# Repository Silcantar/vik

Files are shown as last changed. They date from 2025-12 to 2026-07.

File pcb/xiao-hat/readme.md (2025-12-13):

# XIAO VIK Hat

## Overview

This is a simple PCB to add a VIK connector to a Seeed XIAO microcontroller
board. It is mainly intended for the nRF52840 XIAO variant but probably works
for the other variants as well.

The XIAO is surface-mounted to the hat, which allows the BATT+ pad to be
connected as well as making for a lower-profile assembly.

A solder jumper is provided to select which power source is used for the VIK 5V
pin. By default this pin is connected to the BATT+ pad on the XIAO. The
connection can be changed to the USB 5V pin by severing the default jumper and
soldering the other.

## Fabrication and BOM

For PCB fabrication, you can use the files in the `production` folder.

* `xiao-hat.zip` - the file used to fabricate the pcb
* `bom.csv` - used for PCBA. You can also use the part numbers in this file to look up the exact parts as [lcsc.com](https://lcsc.com)
* `positions.csv` - used for PCBA

Using the 3 files above, this has been tested at [jlcpcb.com](https://jlcpcb.com)
These files were generated by the [KiCAD JLCPCB tools plugin](https://github.com/Bouni/kicad-jlcpcb-tools).

## VIK module certification

| Category | Classification | Response |
| --- | --- | --- |
| FPC connector | Required | :heavy_check_mark: |
| Breakout pins | Recommended | :x: |
| Uses: SPI | Optional | :x: |
| SPI used for SPI only | Strongly recommended | :x: |
| Uses: I2C | Optional | :x: |
| I2C used for I2C only | Strongly Recommended | :x: |
| I2C pull ups | Required | :x: |
| Uses: RGB | Optional | :x: |
| Uses: Extra GPIO 1 | Optional | :x: |
| Uses: Extra GPIO 2 | Optional | :x: |
| Standard PCB Size/Mount | Strongly recommended | :x: |

## PCB images

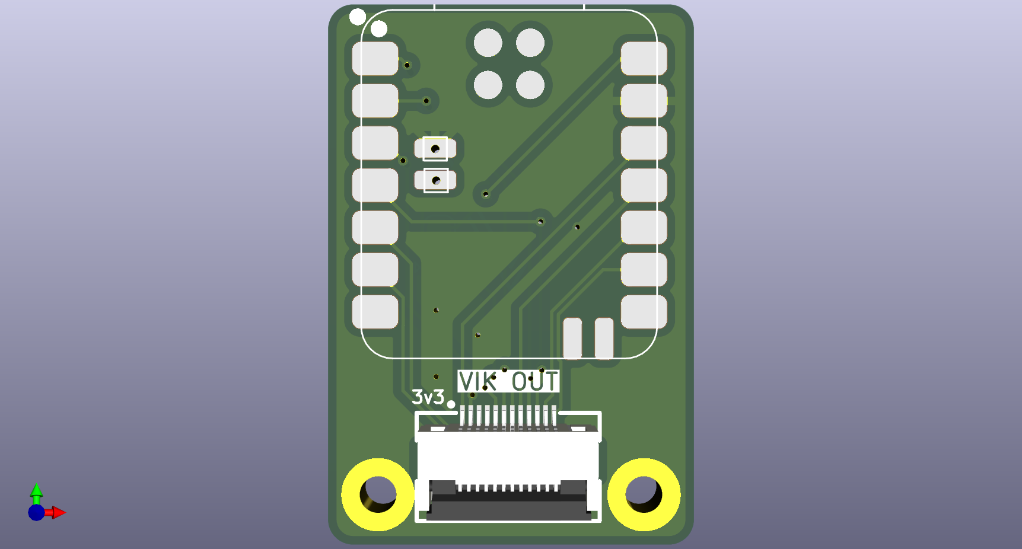
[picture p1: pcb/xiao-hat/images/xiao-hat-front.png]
pcb front


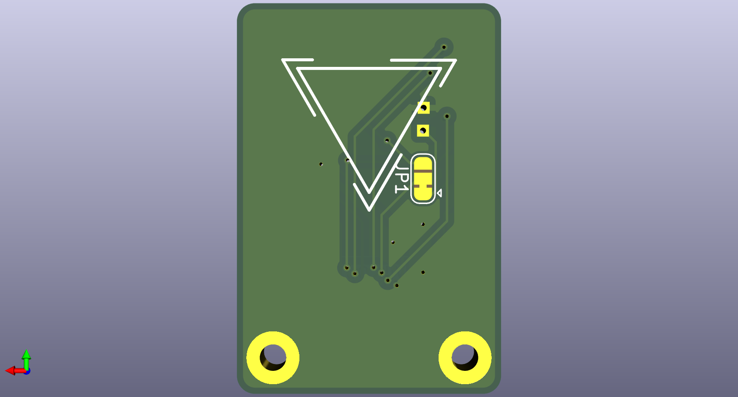
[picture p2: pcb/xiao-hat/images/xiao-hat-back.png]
pcb back


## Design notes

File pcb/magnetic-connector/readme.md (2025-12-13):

# Magnetic Connectors

## Overview

This is a pair of PCBs that adapt a VIK FPC cable to a 12-pin, 2.2mm pitch
magnetic pogo pin connector and back. The pinout of the magnetic connectors is
equivalent to the standard VIK breakout pin layout.

## Fabrication and BOM

For PCB fabrication, you can use the files in the `production` folder.

* `magnetic-connector.zip` - the file used to fabricate the pcb
* `bom.csv` - used for PCBA. You can also use the part numbers in this file to
  look up the exact parts as [lcsc.com](https://lcsc.com)
* `positions.csv` - used for PCBA

Using the 3 files above, this has been tested at [jlcpcb.com](https://jlcpcb.com)

## VIK module certification

| Category | Classification | Response |
| --- | --- | --- |
| FPC connector | Required | :heavy_check_mark: |
| Breakout pins | Recommended | :heavy_check_mark:*|
| Uses: SPI | Optional | :x: |
| SPI used for SPI only | Strongly recommended | :x: |
| Uses: I2C | Optional | :x: |
| I2C used for I2C only | Strongly Recommended | :x: |
| I2C pull ups | Required | :x: |
| Uses: RGB | Optional | :x: |
| Uses: Extra GPIO 1 | Optional | :x: |
| Uses: Extra GPIO 2 | Optional | :x: |
| Standard PCB Size/Mount | Strongly recommended | :x: |

\* If you count the footprint of the magnetic connector.

## PCB images

### horizontal fpc

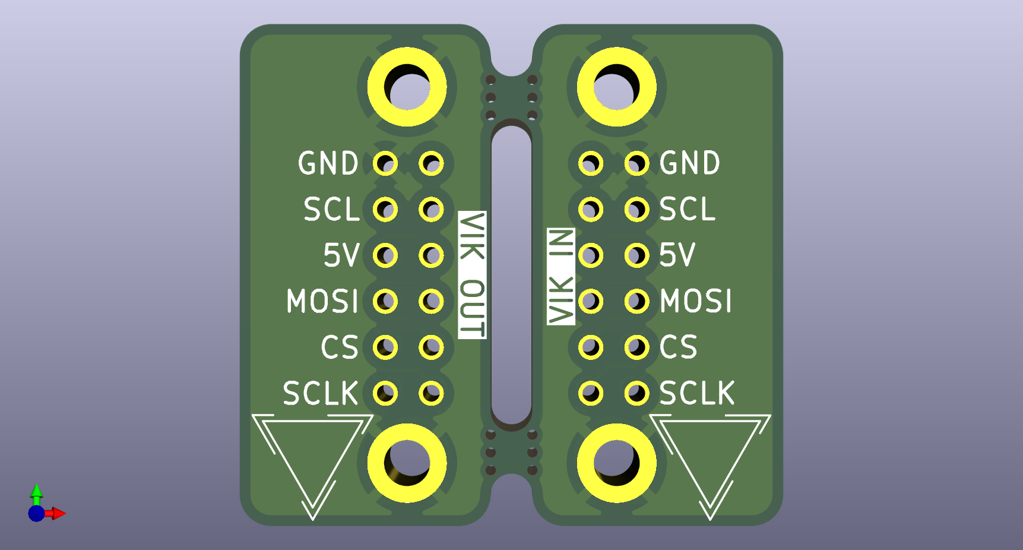
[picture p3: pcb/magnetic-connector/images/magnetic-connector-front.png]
pcb front


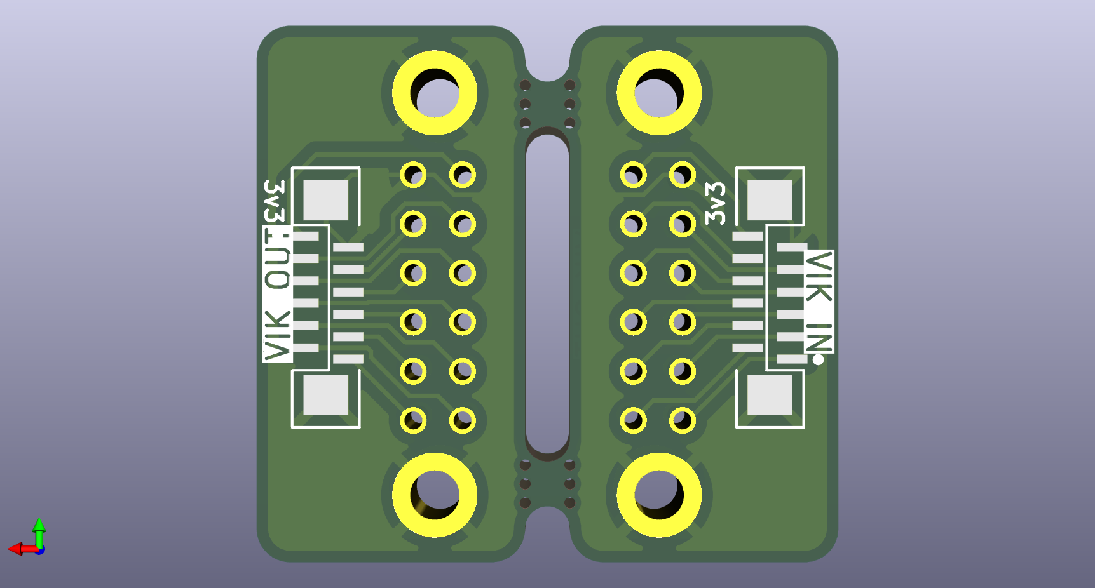
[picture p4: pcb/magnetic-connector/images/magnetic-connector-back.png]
pcb back


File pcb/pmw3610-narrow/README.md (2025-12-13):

# VIK-Compliant PMW3610 Trackball PCB - XXS Version

## Overview

This is a slightly modified version of ykz89's PMW3610-xxs module. The MOTION
pin of the sensor is moved from the VIK MOSI pin to GP2 to make the module
compliant with the VIK standard.

## Fabrication and BOM

For PCB fabrication, you can use the files in the jlcpcb/production_files folder.

* `pmw3610-xxs-compliant.zip` - the file used to fabricate the pcb
* `bom.csv` - used for PCBA. You can also use the part numbers in this file to look up the exact parts as [lcsc.com](https://lcsc.com)
* `positions.csv` - used for PCBA

Using the 3 files above, this has been tested at [jlcpcb.com](https://jlcpcb.com)
These files were generated by the [KiCAD JLCPCB tools plugin](https://github.com/Bouni/kicad-jlcpcb-tools).

## VIK module certification

| Category | Classification | Response |
| --- | --- | --- |
| FPC connector | Required | :heavy_check_mark: |
| Breakout pins | Recommended | :x: |
| Uses: SPI | Optional | :heavy_check_mark: |
| SPI used for SPI only | Strongly recommended | :heavy_check_mark: |
| Uses: I2C | Optional | :x: |
| I2C used for I2C only | Strongly Recommended | :x: |
| I2C pull ups | Required | :x: |
| Uses: RGB | Optional | :x: |
| Uses: Extra GPIO 1 | Optional | :x: |
| Uses: Extra GPIO 2 | Optional | :heavy_check_mark: |
| Standard PCB Size/Mount | Strongly recommended | :x: |

## PCB images

pcb front

pcb back

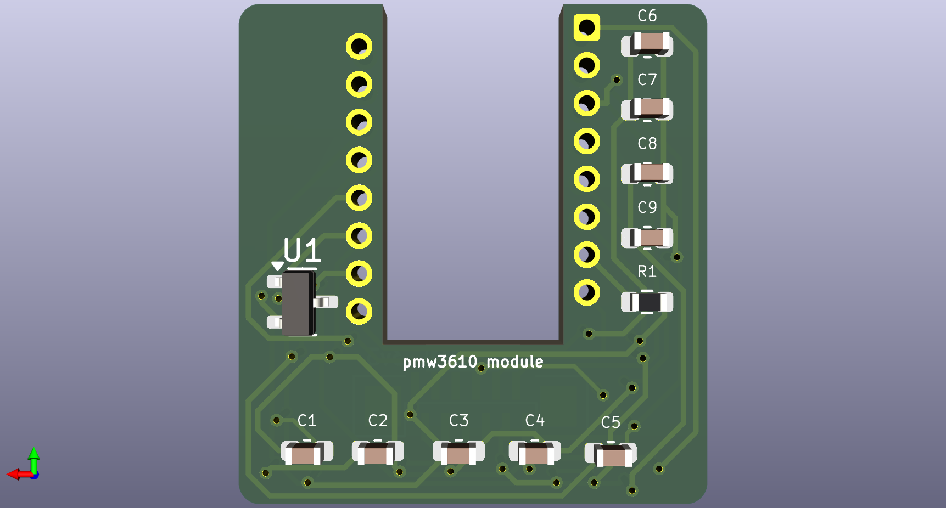
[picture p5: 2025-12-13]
pcb/pmw3610-narrow/images/pmw3610-narrow-back.png

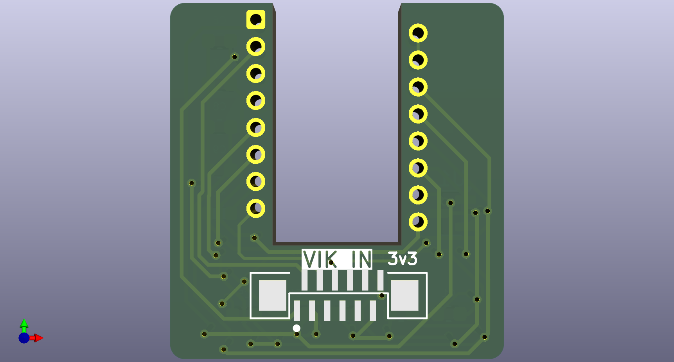
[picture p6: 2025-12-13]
pcb/pmw3610-narrow/images/pmw3610-narrow-front.png

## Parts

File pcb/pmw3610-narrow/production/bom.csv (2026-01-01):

Designator | Footprint | Quantity | Value | LCSC Part #
C1 | 0603 | 1 | 1u | C14663
C2 | 0603 | 1 | 1u | C15849
C3, C8 | 0603 | 2 | 100n | C19666
C4 | 0603 | 1 | 10n | C19666
C5 | 0603 | 1 | 100n (X7R) | C19666
C6 | 0603 | 1 | 10u (X7R) | C19666
C7 | 0603 | 1 | 10n (X7R) | C19666
C9 | 0603 | 1 | 3.3u/25V | C19666
J2 | vik-module-connector-vertical | 1 | vik-module-connector
R1 | 0603 | 1 | 2M | C22976
U1 | SOT-23 | 1 | MCP1700T-1802E/TT | C150796
U2 | PMW3610DM-SUDU 16Pin | 1 | PMW3610

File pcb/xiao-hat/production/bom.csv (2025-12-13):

Designator | Footprint | Quantity | Value | LCSC Part #
J6 | vik-keyboard-connector-horizontal | 1 | VIK_OUT
U4 | XIAO-nRF52840-SMD | 1 | XIAO-nRF52840-SMD

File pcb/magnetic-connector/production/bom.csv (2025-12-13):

Designator | Footprint | Quantity | Value | LCSC Part #
_6, _5, _2, |  | 4
_4, _3 | vik-logo-small | 2 | vik-logo-small
J10 | vik-module-throughole-2.2mm | 1 | MAG_CONN_IN
J7 | vik-module-connector-vertical | 1 | VIK_IN
J8 | vik-keyboard-connector-vertical | 1 | VIK_OUT
J9 | vik-keyboard-throughole-2.2mm | 1 | MAG_CONN_OUT

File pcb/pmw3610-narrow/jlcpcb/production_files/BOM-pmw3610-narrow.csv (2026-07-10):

Comment | Designator | Footprint | LCSC | Quantity
100n | C3,C8 | C_0603_1608Metric_Pad1.08x0.95mm_HandSolder | C14663 | 2
100n (X7R) | C5 | C_0603_1608Metric_Pad1.08x0.95mm_HandSolder | C14663 | 1
10n | C4 | C_0603_1608Metric_Pad1.08x0.95mm_HandSolder | C57112 | 1
10n (X7R) | C7 | C_0603_1608Metric_Pad1.08x0.95mm_HandSolder | C57112 | 1
10u (X7R) | C6 | C_0603_1608Metric_Pad1.08x0.95mm_HandSolder | C19702 | 1
1u | C1,C2 | C_0603_1608Metric_Pad1.08x0.95mm_HandSolder | C15849 | 2
2M | R1 | R_0603_1608Metric_Pad0.98x0.95mm_HandSolder | C2930148 | 1
3.3u/25V | C9 | C_0603_1608Metric_Pad1.08x0.95mm_HandSolder | C51412 | 1
MG6208T3-18 | U1 | SOT-23 | C22395363 | 1
vik-module-connector | J2 | vik-module-connector-horizontal-mini | C2906115 | 1

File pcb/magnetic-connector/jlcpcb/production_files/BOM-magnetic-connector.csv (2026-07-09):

Comment | Designator | Footprint | LCSC | Quantity
CLAMP0504DT | U1,U2,U3,U4,U5,U6 | SOT-23-6 | C2688137 | 6
SMD0805-050-16V | F1,F2,F3,F4 | Fuse_0805_2012Metric | C2833485 | 4
VIK_IN | J_VIK_HOST1 | vik-module-connector-horizontal | C2856799 | 1
VIK_OUT | J_VIK_CLI1 | vik-keyboard-connector-horizontal | C2856799 | 1
MAG_CONN_IN | J_MC_CLI1 | vik-module-throughole-2.2mm |  | 1
MAG_CONN_OUT | J_MC_HOST1 | vik-keyboard-throughole-2.2mm |  | 1

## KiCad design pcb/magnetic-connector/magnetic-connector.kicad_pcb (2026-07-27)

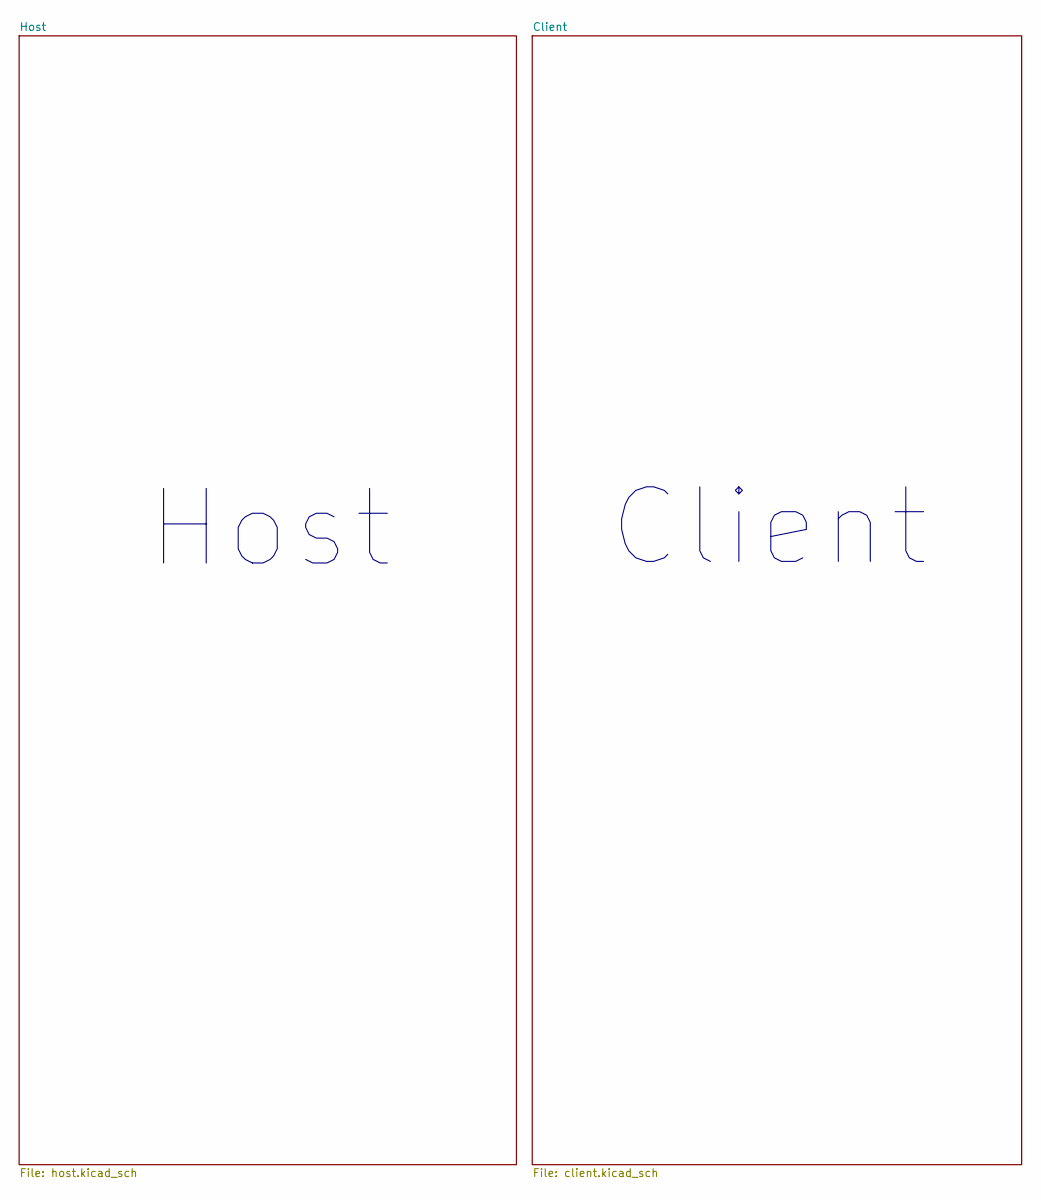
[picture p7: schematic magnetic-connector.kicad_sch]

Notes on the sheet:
Host
Client

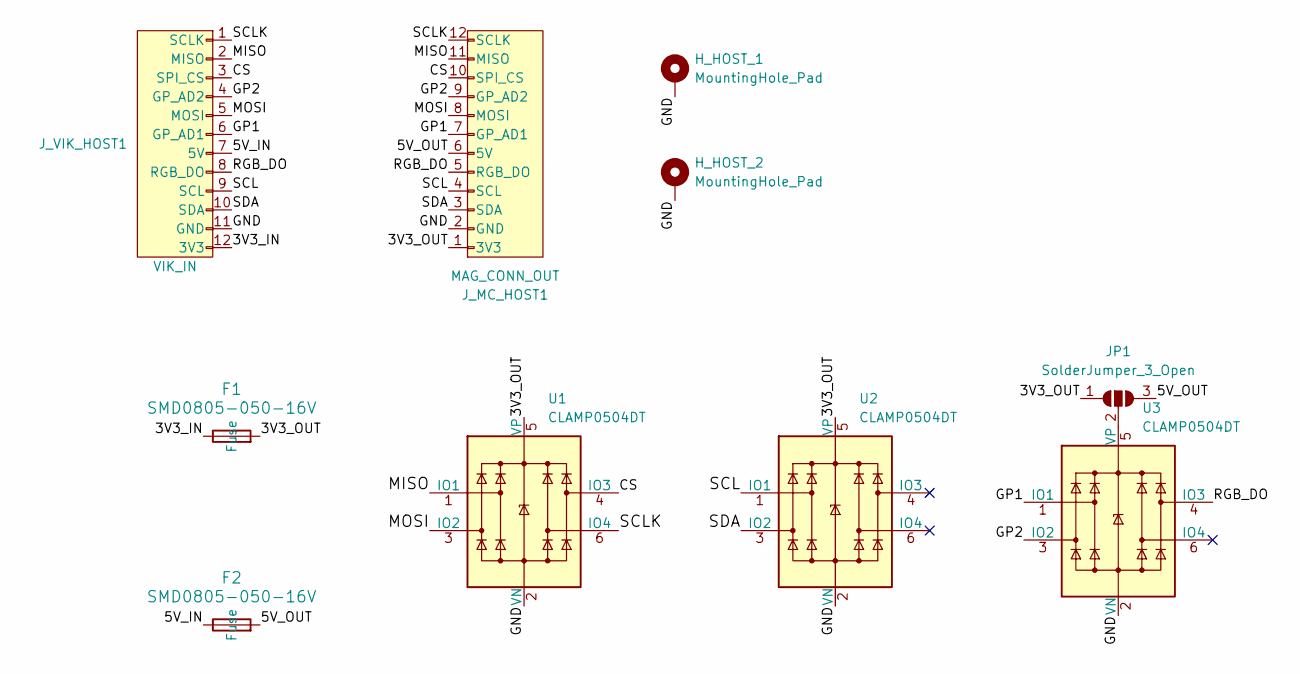
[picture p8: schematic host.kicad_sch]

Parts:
F1, F2: SMD0805-050-16V; Fuse_0805_2012Metric; Manufacturer Part Number SMD0805-050-16V; LCSC Part Number C2833485
H_HOST_1, H_HOST_2: MountingHole_Pad; MountingHole_2.2mm_M2_Pad
JP1: SolderJumper_3_Open; SolderJumper-3_P2.0mm_Open_TrianglePad1.0x1.5mm_NumberLabels
J_MC_HOST1: MAG_CONN_OUT; vik-keyboard-throughole-2.2mm
J_VIK_HOST1: VIK_IN; vik-module-connector-horizontal; LCSC C2856799
U1, U2, U3: CLAMP0504DT; SOT-23-6; LCSC C2688137

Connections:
/Host/3V3_IN: F1.1, J_VIK_HOST1.12 (3V3)
/Host/3V3_OUT: F1.2, JP1.1 (A), J_MC_HOST1.1 (3V3), U1.5 (VP), U2.5 (VP)
/Host/5V_IN: F2.1, J_VIK_HOST1.7 (5V)
/Host/5V_OUT: F2.2, JP1.3 (B), J_MC_HOST1.6 (5V)
/Host/CS: J_MC_HOST1.10 (SPI_CS), J_VIK_HOST1.3 (SPI_CS), U1.4 (IO3)
/Host/GND: H_HOST_1.1 (1_1), H_HOST_2.1 (1_1), J_MC_HOST1.2 (GND), J_VIK_HOST1.11 (GND), J_VIK_HOST1.13, J_VIK_HOST1.14, U1.2 (VN), U2.2 (VN), U3.2 (VN)
/Host/GP1: J_MC_HOST1.7 (GP_AD1), J_VIK_HOST1.6 (GP_AD1), U3.1 (IO1)
/Host/GP2: J_MC_HOST1.9 (GP_AD2), J_VIK_HOST1.4 (GP_AD2), U3.3 (IO2)
/Host/MISO: J_MC_HOST1.11 (MISO), J_VIK_HOST1.2 (MISO), U1.1 (IO1)
/Host/MOSI: J_MC_HOST1.8 (MOSI), J_VIK_HOST1.5 (MOSI), U1.3 (IO2)
/Host/RGB_DO: J_MC_HOST1.5 (RGB_DO), J_VIK_HOST1.8 (RGB_DO), U3.4 (IO3)
/Host/SCL: J_MC_HOST1.4 (SCL), J_VIK_HOST1.9 (SCL), U2.1 (IO1)
/Host/SCLK: J_MC_HOST1.12 (SCLK), J_VIK_HOST1.1 (SCLK), U1.6 (IO4)
/Host/SDA: J_MC_HOST1.3 (SDA), J_VIK_HOST1.10 (SDA), U2.3 (IO2)
unnamed: JP1.2 (C), U3.5 (VP)

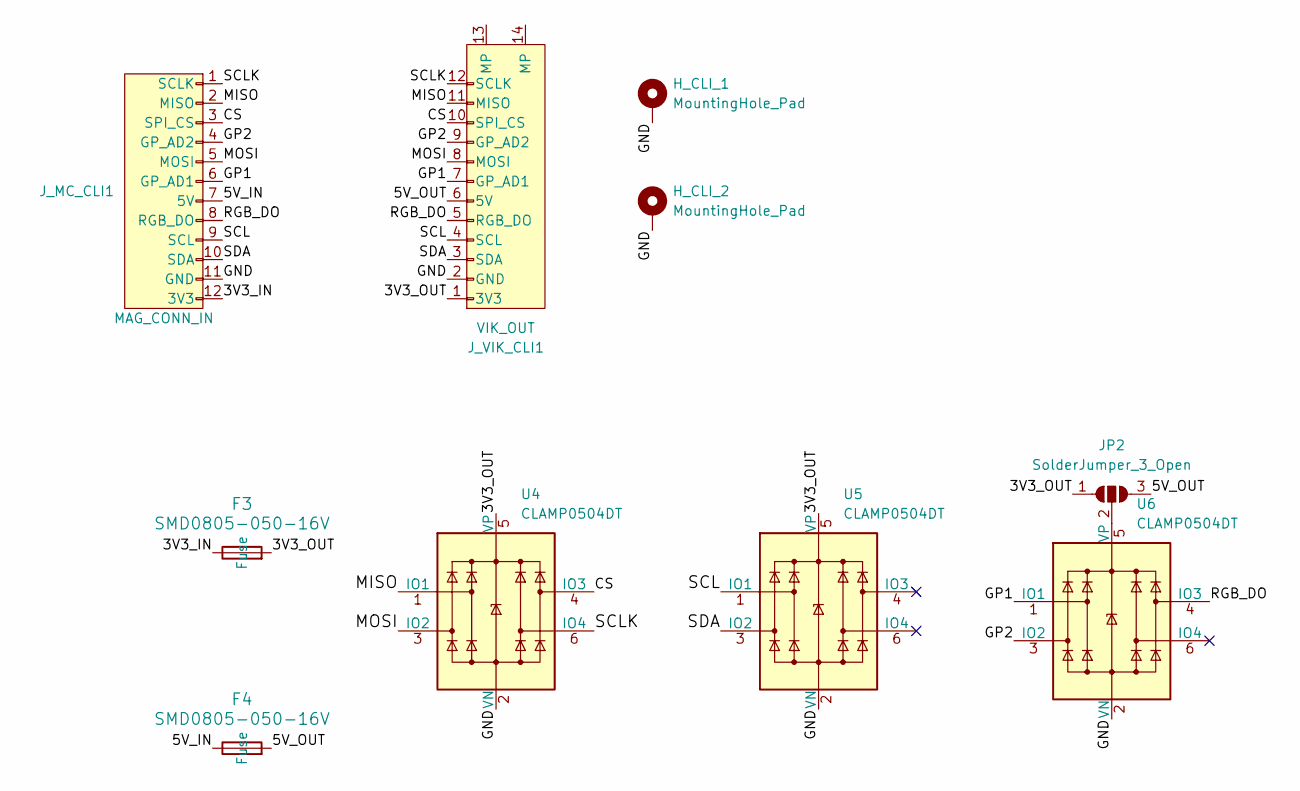
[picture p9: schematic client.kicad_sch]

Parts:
F3, F4: SMD0805-050-16V; Fuse_0805_2012Metric; Manufacturer Part Number SMD0805-050-16V; LCSC Part Number C2833485
H_CLI_1, H_CLI_2: MountingHole_Pad; MountingHole_2.2mm_M2_Pad
JP2: SolderJumper_3_Open; SolderJumper-3_P2.0mm_Open_TrianglePad1.0x1.5mm_NumberLabels
J_MC_CLI1: MAG_CONN_IN; vik-module-throughole-2.2mm
J_VIK_CLI1: VIK_OUT; vik-keyboard-connector-horizontal; LCSC C2856799
U4, U5, U6: CLAMP0504DT; SOT-23-6; LCSC C2688137

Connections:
/Client/3V3_IN: F3.1, J_MC_CLI1.12 (3V3)
/Client/3V3_OUT: F3.2, JP2.1 (A), J_VIK_CLI1.1 (3V3), U4.5 (VP), U5.5 (VP)
/Client/5V_IN: F4.1, J_MC_CLI1.7 (5V)
/Client/5V_OUT: F4.2, JP2.3 (B), J_VIK_CLI1.6 (5V)
/Client/CS: J_MC_CLI1.3 (SPI_CS), J_VIK_CLI1.10 (SPI_CS), U4.4 (IO3)
/Client/GND: H_CLI_1.1 (1_1), H_CLI_2.1 (1_1), J_MC_CLI1.11 (GND), J_VIK_CLI1.2 (GND), J_VIK_CLI1.13 (MP), J_VIK_CLI1.14 (MP), U4.2 (VN), U5.2 (VN), U6.2 (VN)
/Client/GP1: J_MC_CLI1.6 (GP_AD1), J_VIK_CLI1.7 (GP_AD1), U6.1 (IO1)
/Client/GP2: J_MC_CLI1.4 (GP_AD2), J_VIK_CLI1.9 (GP_AD2), U6.3 (IO2)
/Client/MISO: J_MC_CLI1.2 (MISO), J_VIK_CLI1.11 (MISO), U4.1 (IO1)
/Client/MOSI: J_MC_CLI1.5 (MOSI), J_VIK_CLI1.8 (MOSI), U4.3 (IO2)
/Client/RGB_DO: J_MC_CLI1.8 (RGB_DO), J_VIK_CLI1.5 (RGB_DO), U6.4 (IO3)
/Client/SCL: J_MC_CLI1.9 (SCL), J_VIK_CLI1.4 (SCL), U5.1 (IO1)
/Client/SCLK: J_MC_CLI1.1 (SCLK), J_VIK_CLI1.12 (SCLK), U4.6 (IO4)
/Client/SDA: J_MC_CLI1.10 (SDA), J_VIK_CLI1.3 (SDA), U5.3 (IO2)
unnamed: JP2.2 (C), U6.5 (VP)

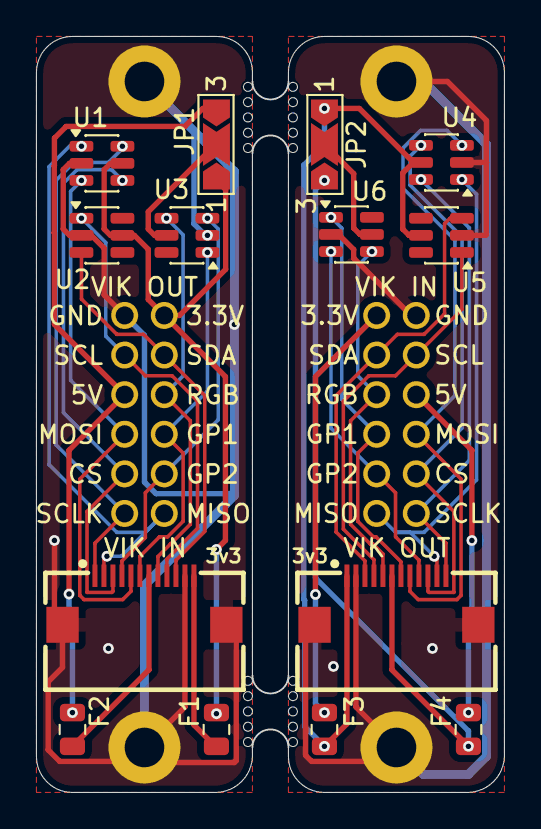
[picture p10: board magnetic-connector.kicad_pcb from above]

Board: 2 copper layers, 26.0 x 42.0 mm, 20 parts (0 on the bottom side), 30 nets.

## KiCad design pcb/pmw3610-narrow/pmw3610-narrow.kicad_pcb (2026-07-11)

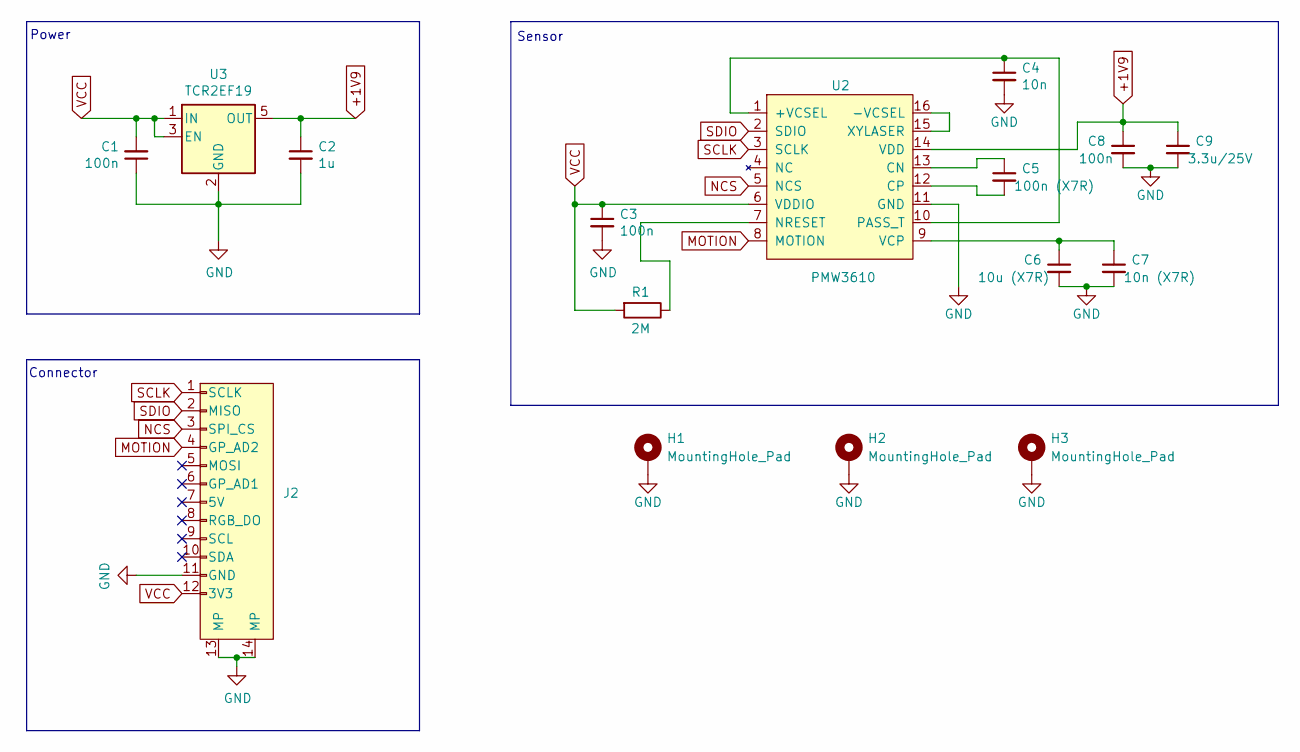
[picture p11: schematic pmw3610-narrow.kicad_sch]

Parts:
C1: 100n; C_0805_2012Metric_Pad1.18x1.45mm_HandSolder; LCSC C15849
C2: 1u; C_0805_2012Metric_Pad1.18x1.45mm_HandSolder; LCSC C15849
C3, C8: 100n; C_0805_2012Metric_Pad1.18x1.45mm_HandSolder; LCSC C14663
C4: 10n; C_0805_2012Metric_Pad1.18x1.45mm_HandSolder; LCSC C57112
C5: 100n (X7R); C_0805_2012Metric_Pad1.18x1.45mm_HandSolder; LCSC C14663
C6: 10u (X7R); C_0805_2012Metric_Pad1.18x1.45mm_HandSolder; LCSC C19702
C7: 10n (X7R); C_0805_2012Metric_Pad1.18x1.45mm_HandSolder; LCSC C57112
C9: 3.3u/25V; C_0805_2012Metric_Pad1.18x1.45mm_HandSolder; LCSC C51412
H1, H2, H3: MountingHole_Pad; MountingHole_2.2mm_M2_Pad
J2: vik-module-connector; vik-module-connector-horizontal-mini; LCSC C5213732
R1: 2M; R_0805_2012Metric_Pad1.20x1.40mm_HandSolder; LCSC C2930148
U2: PMW3610; PMW3610DM-SUDU 16Pin
U3: TCR2EF19; SOT-23-5; LCSC C146366

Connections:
+1V9: C2.1, C8.1, C9.1, U2.14 (VDD), U3.5 (OUT)
GND: C1.1, C2.2, C3.2, C4.2, C6.2, C7.2, C8.2, C9.2, H1.1 (1_1), H2.1 (1_1), H3.1 (1_1), J2.11 (GND), J2.13 (MP), J2.14 (MP), U2.11 (GND), U3.2 (GND)
MOTION: J2.4 (GP_AD2), U2.8 (MOTION)
NCS: J2.3 (SPI_CS), U2.5 (NCS)
unnamed: C4.1, U2.1 (+VCSEL), U2.10 (PASS_T)
unnamed: U2.15 (XYLASER), U2.16 (-VCSEL)
unnamed: C5.1, U2.13 (CN)
unnamed: C5.2, U2.12 (CP)
unnamed: R1.1, U2.7 (NRESET)
unnamed: C6.1, C7.1, U2.9 (VCP)
SCLK: J2.1 (SCLK), U2.3 (SCLK)
SDIO: J2.2 (MISO), U2.2 (SDIO)
VCC: C1.2, C3.1, J2.12 (3V3), R1.2, U2.6 (VDDIO), U3.1 (IN), U3.3 (EN)

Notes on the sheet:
Sensor
Connector
Power

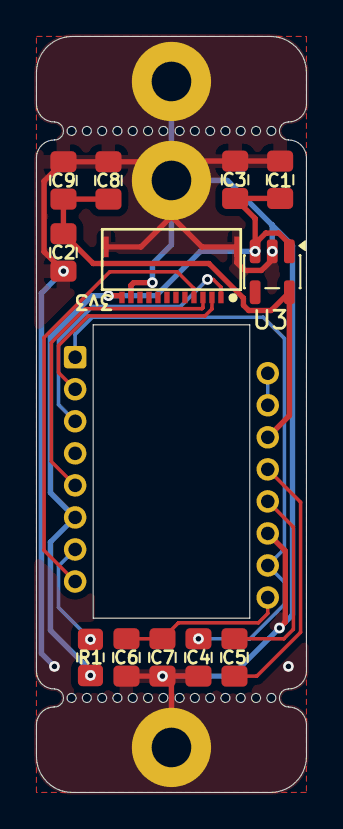
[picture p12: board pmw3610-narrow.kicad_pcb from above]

Board: 2 copper layers, 15.0 x 42.0 mm, 16 parts (0 on the bottom side), 13 nets.

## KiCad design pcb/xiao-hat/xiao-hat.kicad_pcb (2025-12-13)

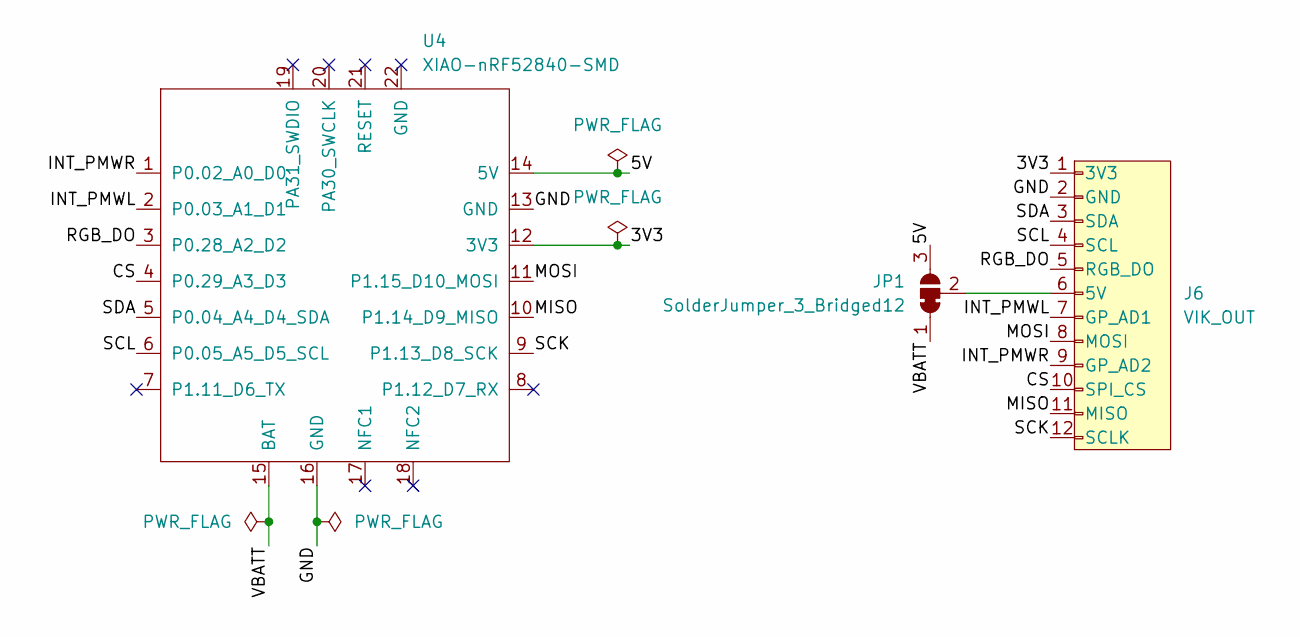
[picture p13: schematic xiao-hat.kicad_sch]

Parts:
J6: VIK_OUT; vik-keyboard-connector-horizontal
JP1: SolderJumper_3_Bridged12; SolderJumper-3_P1.3mm_Bridged12_RoundedPad1.0x1.5mm
U4: XIAO-nRF52840-SMD

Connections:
/3V3: J6.1 (3V3), U4.12 (3V3)
/5V: JP1.3 (B), U4.14 (5V)
/CS: J6.10 (SPI_CS), U4.4 (P0.29_A3_D3)
/GND: J6.2 (GND), U4.13 (GND), U4.16 (GND)
/INT_PMWL: J6.7 (GP_AD1), U4.2 (P0.03_A1_D1)
/INT_PMWR: J6.9 (GP_AD2), U4.1 (P0.02_A0_D0)
/MISO: J6.11 (MISO), U4.10 (P1.14_D9_MISO)
/MOSI: J6.8 (MOSI), U4.11 (P1.15_D10_MOSI)
/RGB_DO: J6.5 (RGB_DO), U4.3 (P0.28_A2_D2)
/SCK: J6.12 (SCLK), U4.9 (P1.13_D8_SCK)
/SCL: J6.4 (SCL), U4.6 (P0.05_A5_D5_SCL)
/SDA: J6.3 (SDA), U4.5 (P0.04_A4_D4_SDA)
/VBATT: JP1.1 (A), U4.15 (BAT)
unnamed: J6.6 (5V), JP1.2 (C)

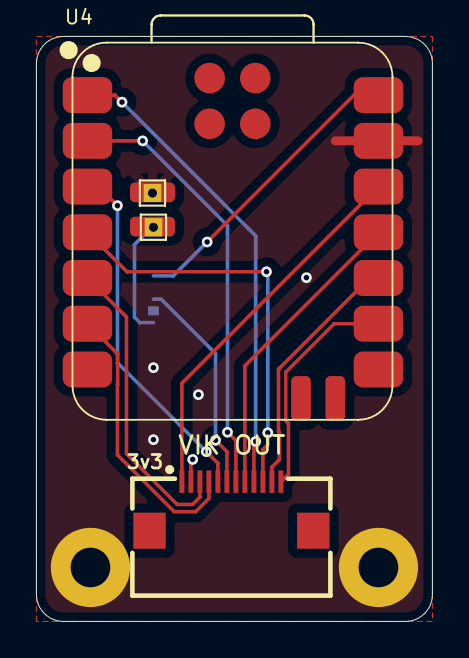
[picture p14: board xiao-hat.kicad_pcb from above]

Board: 2 copper layers, 22.0 x 32.5 mm, 3 parts (1 on the bottom side), 14 nets.

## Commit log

2025-12-13 Create VIK-compliant version of the PMW3610-xxs module.
    [bom.csv, designators.csv, pmw3610-xxs-compliant.kicad_pcb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]
2025-12-13 Create a pair of modules for adapting the VIK bus to magnetic pogo pin connectors.
    [bom.csv, designators.csv, magnetic-connector.kicad_pcb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]
2025-12-13 Create a PCB for adding a VIK keyboard connector to a Seeed XIAO microcontroller.
    [bom.csv, designators.csv, positions.csv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]
2026-01-01 Create narrow PMW3610 module.
    [bom.csv, designators.csv, pmw3610-xxs-compliant-narrow.kicad_pcb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]
2026-01-02 Add more dimensions to pmw3610-xxs-compliant-narrow PCB.
    [pmw3610-xxs-compliant-narrow.kicad_pcb]
2026-01-09 Add more dimensions to magnetic connector PCB.
    [magnetic-connector.kicad_pcb]
2026-05-18 Make magnetic connector size compliant with VIK small form factor.
    [client.kicad_sch, host.kicad_sch, magnetic-connector.kicad_pcb]
2026-05-18 Make PMW-3610-narrow module compliant with VIK small form factor.
    [pmw3610-xxs-compliant-narrow.kicad_pcb]
2026-05-21 Add ESD protection to magnetic connector module.
    [client.kicad_sch, host.kicad_sch, magnetic-connector.kicad_pcb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]
2026-05-23 Change VIK connector and ESD protection chips.
    [client.kicad_sch, host.kicad_sch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]
2026-05-23 Change VIK connector on trackball sensor module.
    [pmw3610-xxs-compliant-narrow-B_Cu.gbr, pmw3610-xxs-compliant-narrow-B_Mask.gbr, pmw3610-xxs-compliant-narrow-B_Paste.gbr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]
2026-07-04 Reduce PMW-3610-narrow PCB width from 16mm to 15mm.
    [pmw3610-xxs-compliant-narrow.kicad_pcb]
2026-07-04 Clean up PMW3610-narrow silkscreens.
    [pmw3610-xxs-compliant-narrow.kicad_pcb]
2026-07-08 Add LCSC part numbers to pmw3610-narrow.
    [BOM-pmw3610-xxs-compliant-narrow.csv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]
2026-07-09 Change ESD protection chips on magnetic connector.
    [BOM-magnetic-connector.csv, client.kicad_sch, host.kicad_sch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]
2026-07-10 Add more ground vias to PMW3610-narrow.
    [pmw3610-xxs-compliant-narrow.kicad_pcb]
2026-07-10 Change voltage regulator on PMW3610-narrow.
    [pmw3610-narrow.kicad_pcb, pmw3610-narrow.kicad_sch]
2026-07-11 Change passives to 0805 footprint.
    [pmw3610-narrow.kicad_pcb, pmw3610-narrow.kicad_sch]
2026-07-27 Increase hole size on magnetic connector PCB.
    [magnetic-connector.kicad_pcb]
2026-08-05 Modify KiCAD symbols and footprints to clean up ERC and DRC warnings.
    Symbols:
    - Add mounting point pin (#13).
    Footprints:
    - Assign mounting pads in footprint to #13 to match symbols.
    - Increase "3v3" text size to 0.8mm.
    - Add courtyards.
